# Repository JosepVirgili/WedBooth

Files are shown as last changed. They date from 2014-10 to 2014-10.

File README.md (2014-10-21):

# Wedding PhotoBooth

A nice weeding PhotoBooth for Sandra and Josep's wedding.

### Required Hardware
The required components are:

- Raspberry Pi (RPi)
- Display (about 10') with HDMI input
- HDMI cable (to connect the RPi with the display)
- Pi Camera
- Nicer camera as a DSLR
- Remote shutter for the DSLR
- USB connector for the DSLR
- Protoboard
- Jumper cables
- Push button 

### Set-up

First the RPi needs to be configured. Follow this [guide]().

When done install gphoto2:

```
wget https://raw.githubusercontent.com/gonzalo/gphoto2-updater/master/gphoto2-updater.sh
chmod +x gphoto2-updater.sh
sudo ./gphoto2-updater.sh
```

Install the bluetooth tools required to operate the PoGo printer:

```
sudo apt-get install bluez bluez-utils obexftp
```

Find the mac adress of your printer:

```
hcitool scan
```

The mac adress will appear as YY:YY:YY:YY:YY:YY Polaroid ZZ ZZ ZZ where YY:YY:YY:YY:YY:YY is the mac adress.
Then we need to include the pin code of the pogo into the system:

```
sudo mkdir /var/lib/bluetooth/YY:YY:YY:YY:YY:YY
sudo nano /var/lib/bluetooth/YY:YY:YY:YY:YY:YY/pincodes
```

Include the line `YY:YY:YY:YY:YY:YY 6000` into the file and save.

Then the software needs to be uploaded into the Raspberry Pi:

```
git clone https://github.com/JosepVirgili/WedBooth.git
```

Then, create a `settings.txt` file to save the PoGo mac adress.

```
cd WedBooth
nano settings.txt
```

Add at the beginning of the file insert the YY:YY:YY:YY:YY:YY mac adress of your PoGo.

### Start the photo-booth software

To start the software just:

```
cd WedBooth
sudo python PhotoBooth.py
```

If you want the software to start when booting then:

```
sudo nano /etc/rc.local
```

At the end of the file add (change pi for your own username if you have change it):

```
# Auto run WedBooth
cd /home/pi/WedBooth
sudo python /home/pi/WedBooth/PhotoBooth.py
```

### Legal Boring Stuff

Copyright 2014 Josep Virgili Llop

This program is free software: you can redistribute it and/or modify
it under the terms of the GNU General Public License as published by
the Free Software Foundation, either version 3 of the License, or
(at your option) any later version.

This program is distributed in the hope that it will be useful,
but WITHOUT ANY WARRANTY; without even the implied warranty of
MERCHANTABILITY or FITNESS FOR A PARTICULAR PURPOSE.  See the
GNU General Public License for more details.

You should have received a copy of the GNU General Public License
along with this program.  If not, see <http://www.gnu.org/licenses/>.

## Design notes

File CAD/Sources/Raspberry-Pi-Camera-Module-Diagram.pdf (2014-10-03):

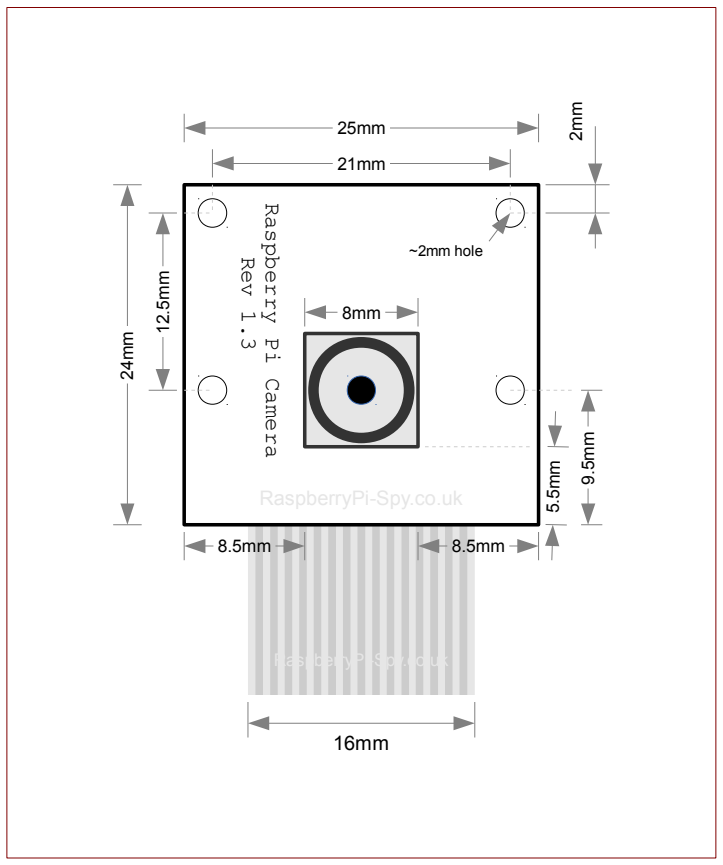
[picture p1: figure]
RaspberryPi-Spy.co.uk; Rasp; berry Pi Camera Rev 1.3; ~2mm hole

Print so that rectangle is 50mm x 60mm This will require a reduction of 50%

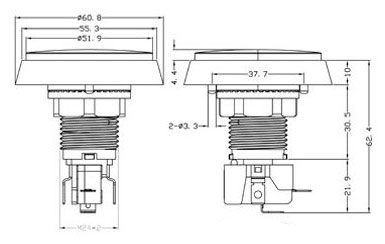
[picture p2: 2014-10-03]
CAD/Sources/Button.jpg

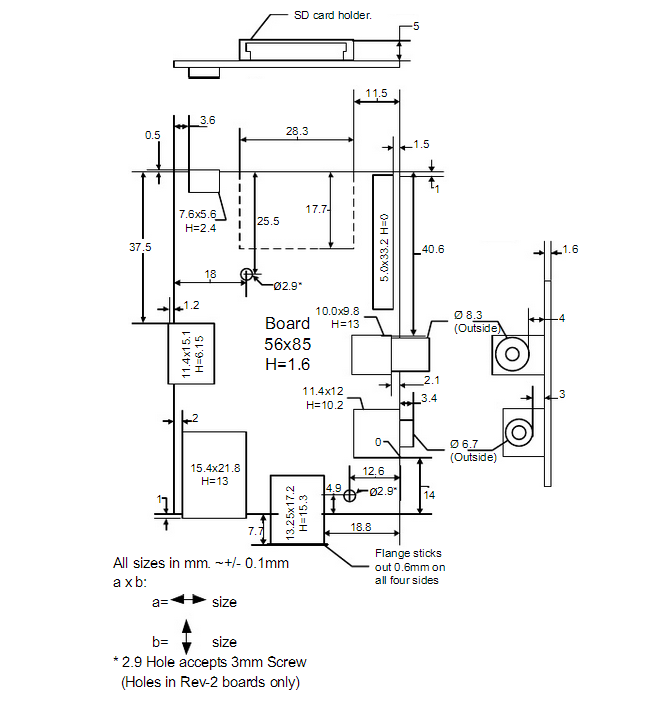
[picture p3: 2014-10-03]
CAD/Sources/PiMeasurments.png

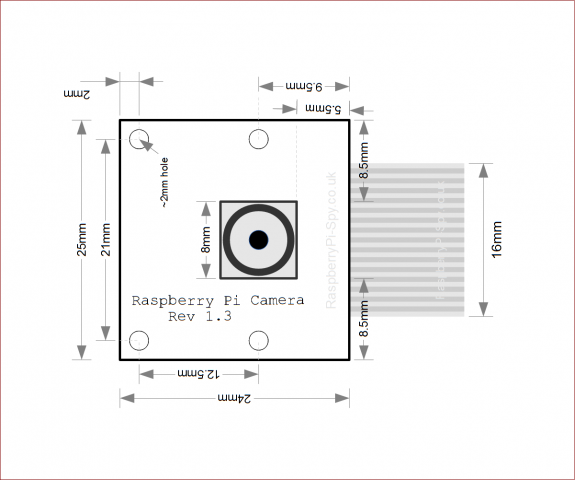
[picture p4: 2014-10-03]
CAD/Sources/Raspberry-Pi-Camera-Module-Diagram-575x480.png

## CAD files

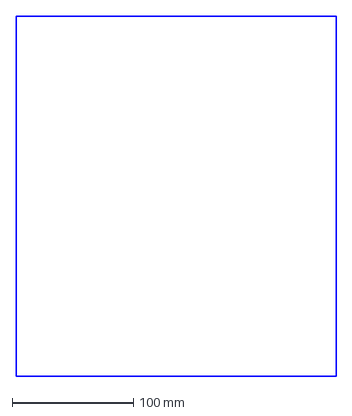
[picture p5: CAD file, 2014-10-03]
CAD/2DCAD/NoComments/Back_NoCom.dxf
264.0 x 297.0 mm

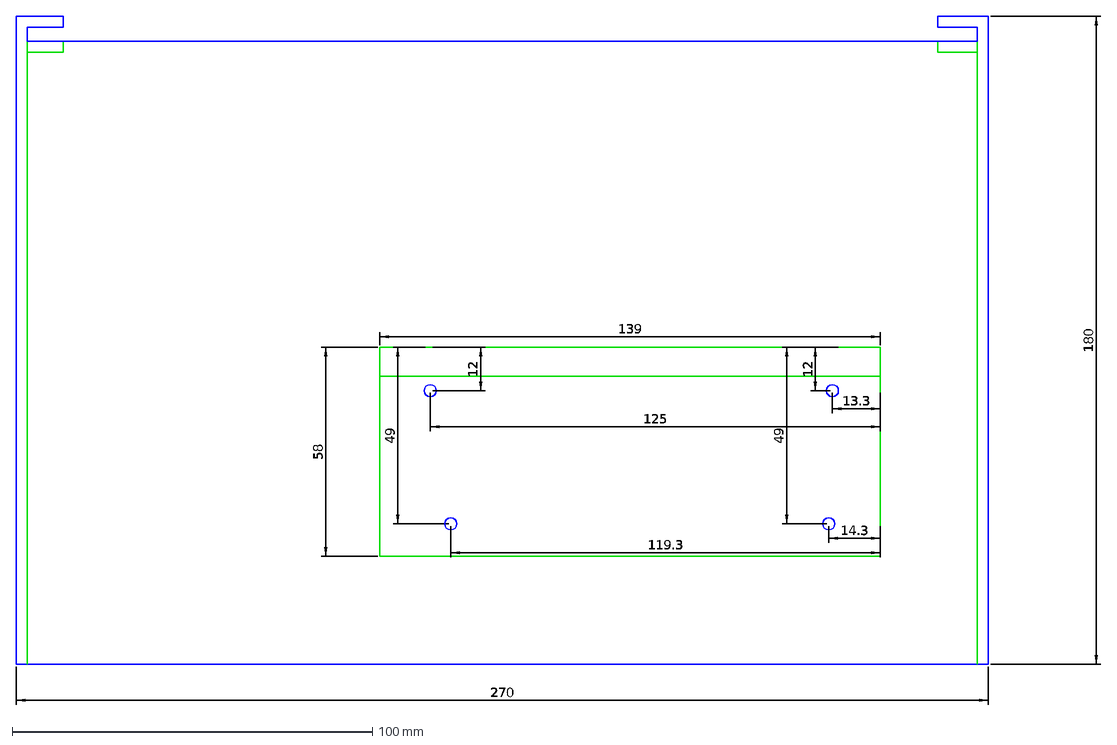
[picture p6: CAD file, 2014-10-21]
CAD/2DCAD/Top.dxf
270
12
125
49
14.3
13.3
119.3
180
139
58

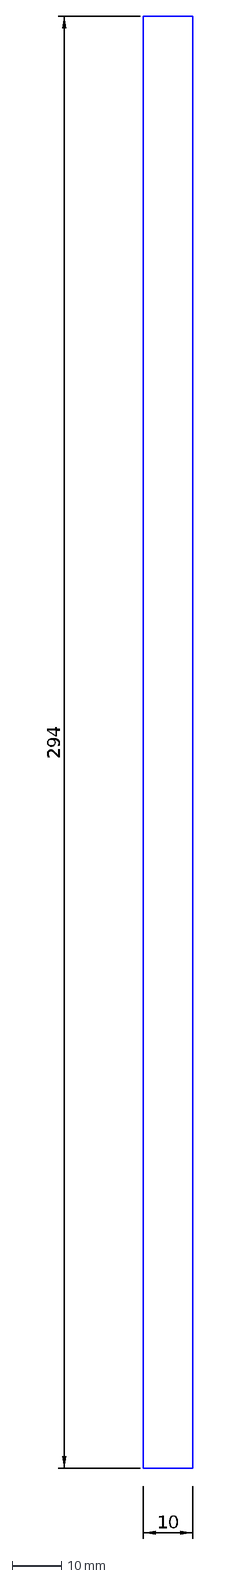
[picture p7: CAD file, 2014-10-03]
CAD/2DCAD/Block_Back_x4.dxf
10
294

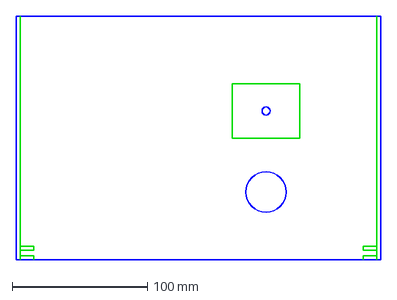
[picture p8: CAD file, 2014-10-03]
CAD/2DCAD/NoComments/Bottom_NoCom.dxf
270.0 x 180.0 mm

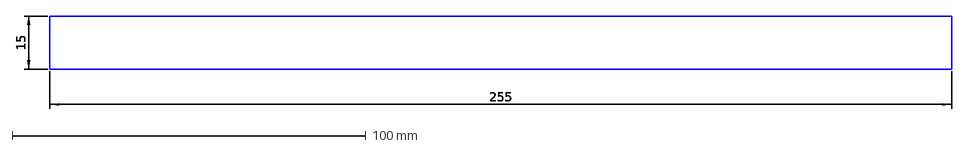
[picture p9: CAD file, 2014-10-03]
CAD/2DCAD/Block_Front_x4.dxf
255
15

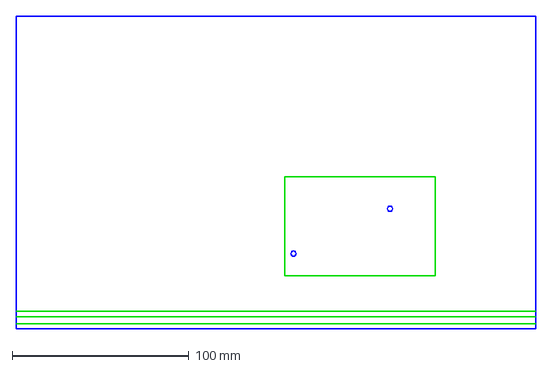
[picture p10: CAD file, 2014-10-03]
CAD/2DCAD/NoComments/Right_NoCom.dxf
294.0 x 177.0 mm

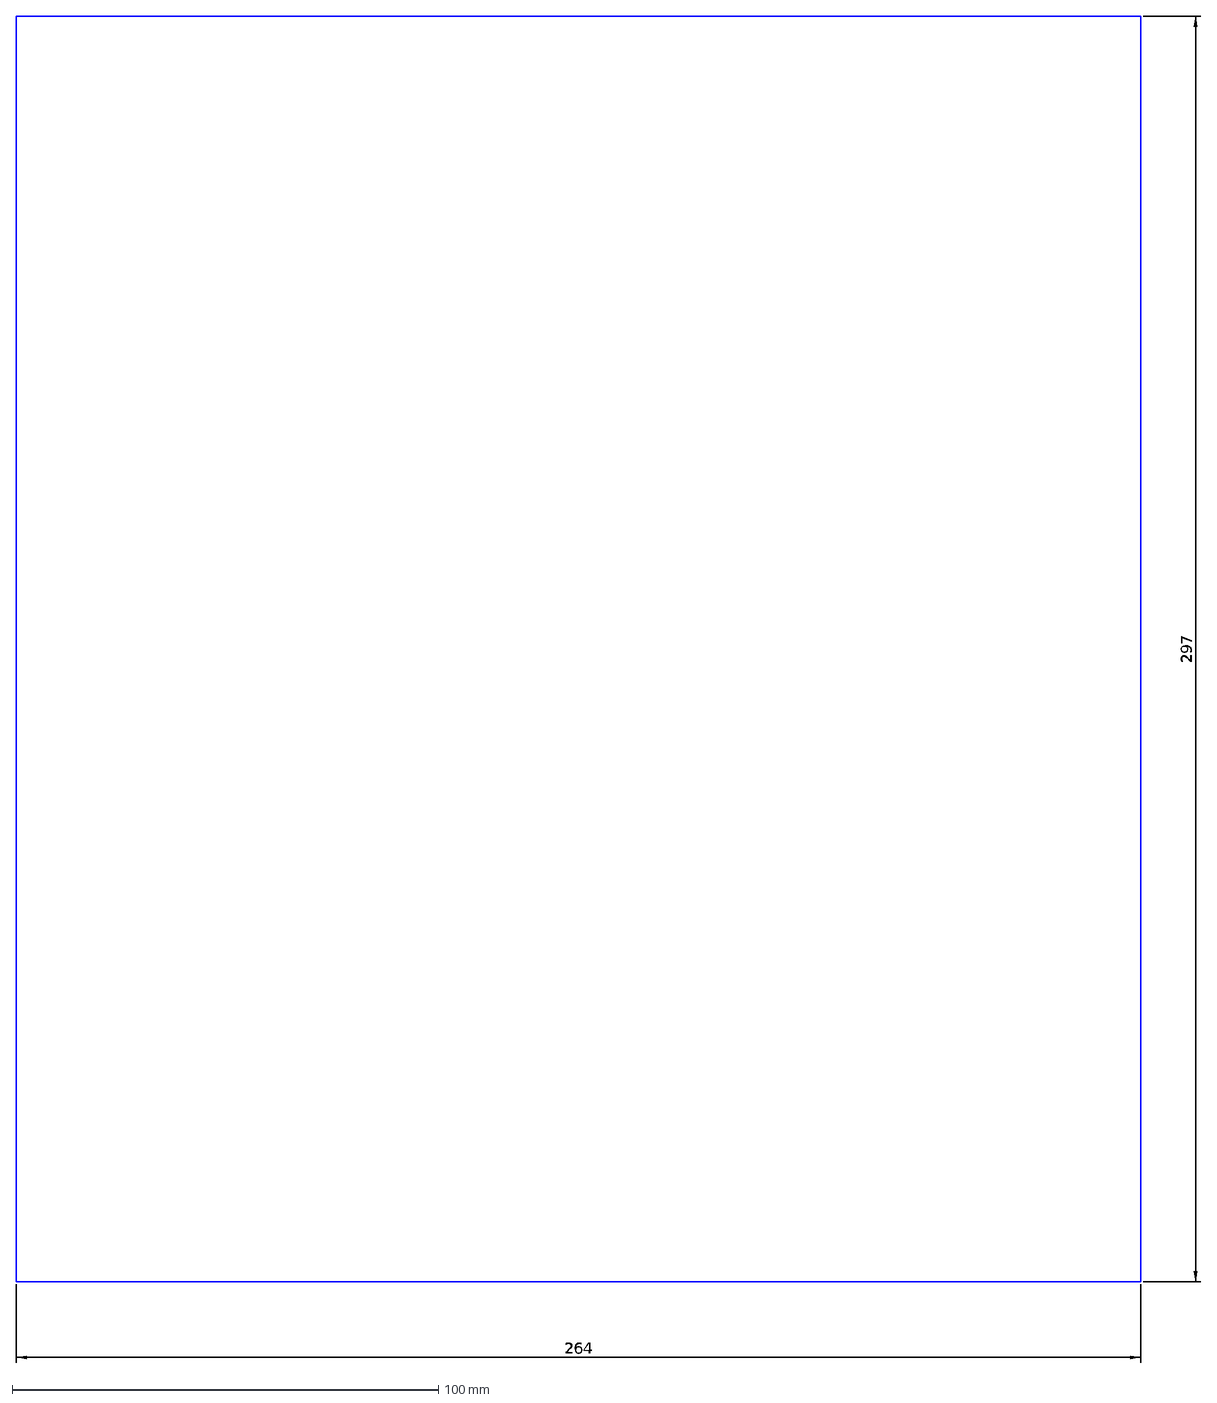
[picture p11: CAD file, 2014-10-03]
CAD/2DCAD/Back.dxf
297
264

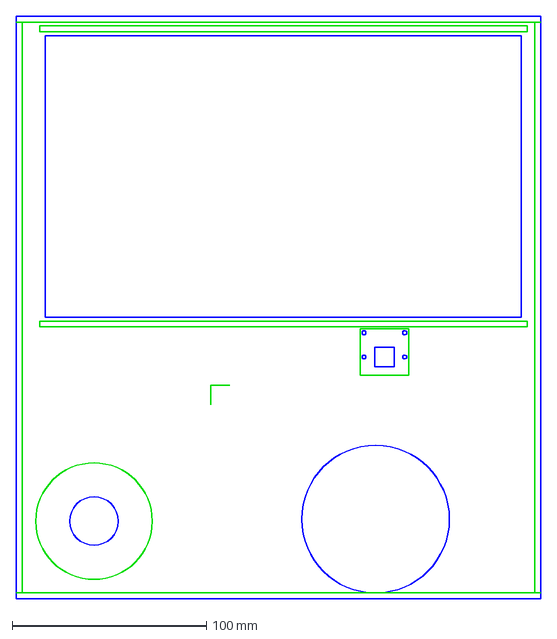
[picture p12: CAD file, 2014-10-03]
CAD/2DCAD/NoComments/Front_NoCom.dxf
270.0 x 300.0 mm

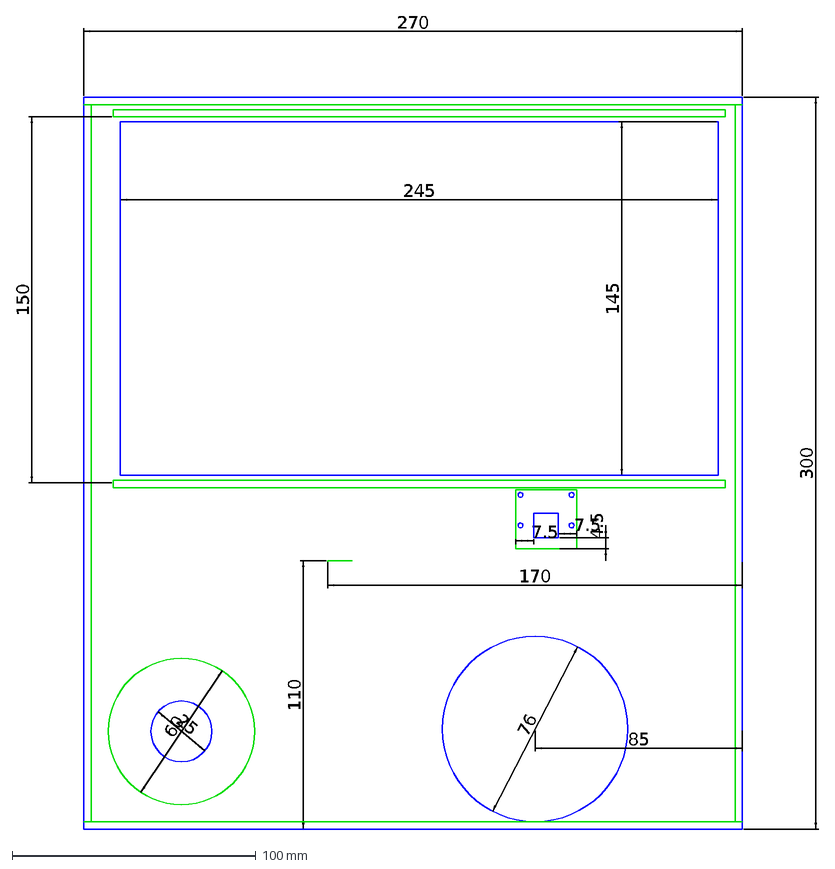
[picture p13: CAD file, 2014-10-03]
CAD/2DCAD/Front.dxf
300
245
110
170
270
150
145
4.5
7.5
60
25
85
76

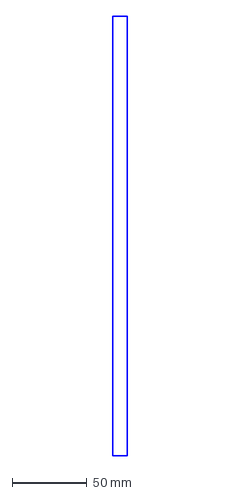
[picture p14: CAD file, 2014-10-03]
CAD/2DCAD/NoComments/Block_Back_x4_NoCom.dxf
10.0 x 294.0 mm

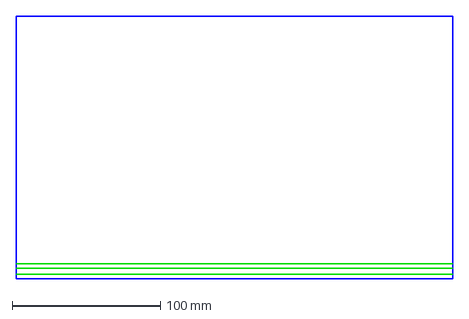
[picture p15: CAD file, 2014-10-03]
CAD/2DCAD/NoComments/Left_NoCom.dxf
294.0 x 177.0 mm

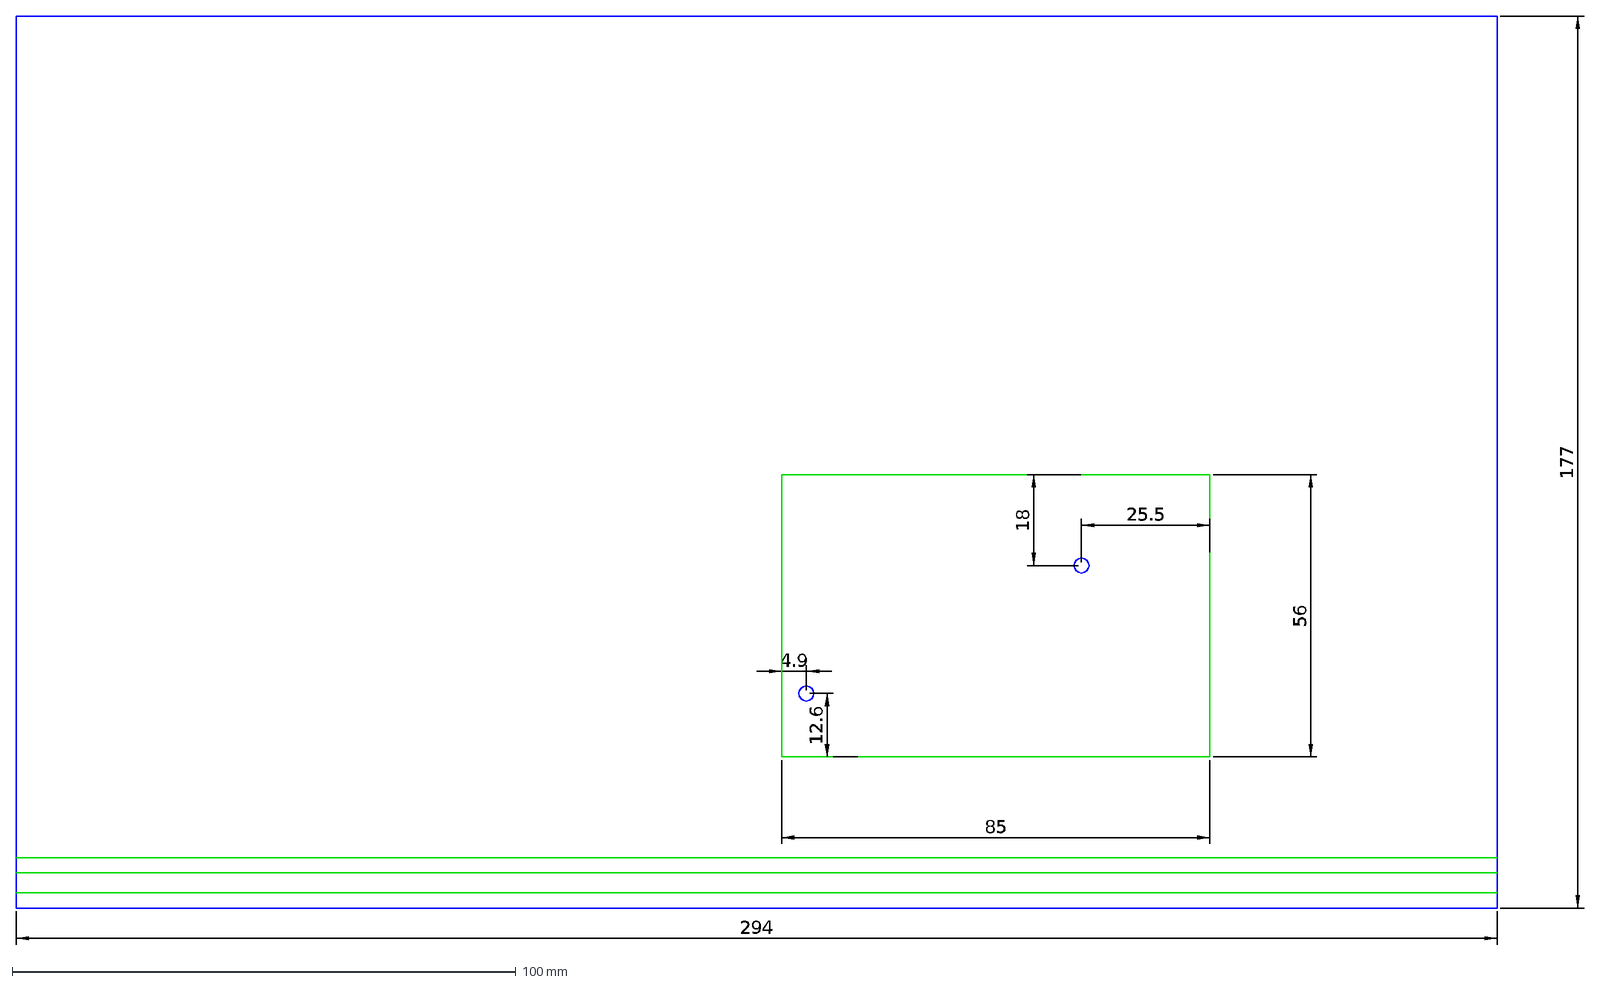
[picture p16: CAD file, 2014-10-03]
CAD/2DCAD/Right.dxf
294
177
85
12.6
4.9
56
25.5
18

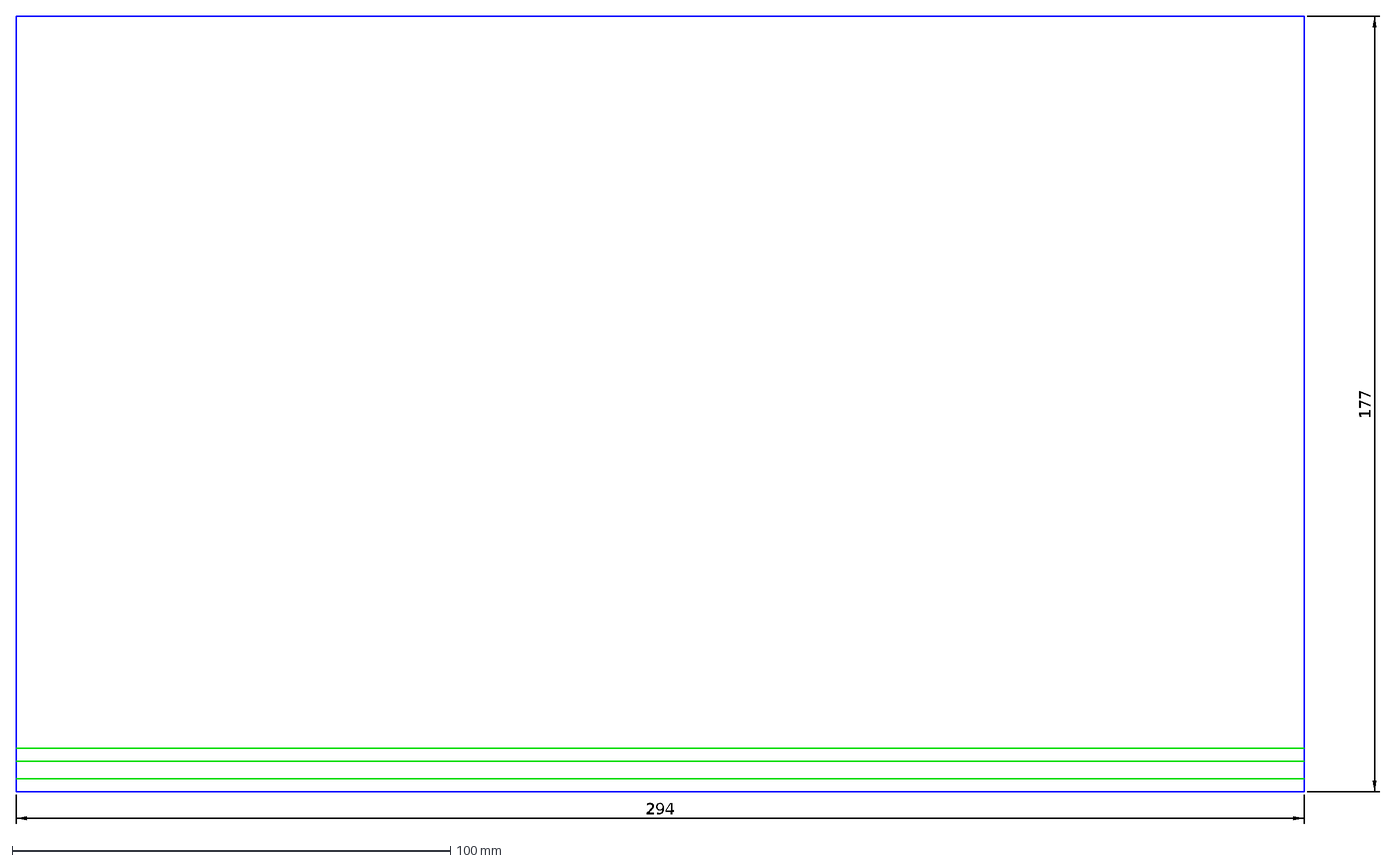
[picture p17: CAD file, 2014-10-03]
CAD/2DCAD/Left.dxf
294
177

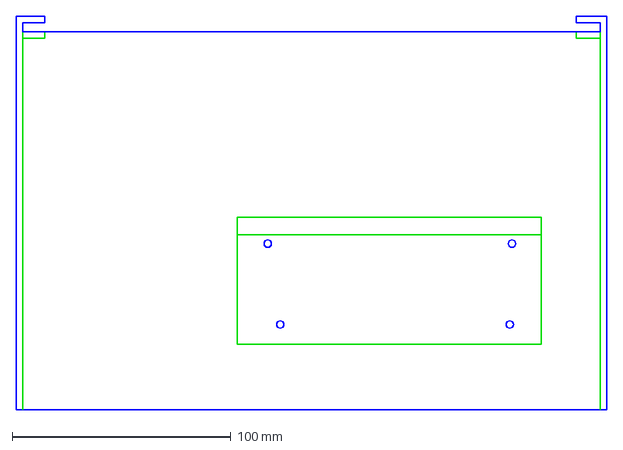
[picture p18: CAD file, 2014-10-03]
CAD/2DCAD/NoComments/Top_NoCom.dxf
270.0 x 180.0 mm

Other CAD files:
CAD/2DCAD/Bottom.dxf
CAD/2DCAD/NoComments/Block_Front_x4_NoCom.dxf

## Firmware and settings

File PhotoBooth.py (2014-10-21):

# Wedding Photo Booth Software
#
#    Copyright 2014 Josep Virgili Llop
#
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
#--- CODE ---#
import RPi.GPIO as GPIO
import time
from subprocess import call
import pygame
import picamera
import math
import io
from threading import Thread

#GPIO configuration
GPIO.setmode(GPIO.BOARD) #Set the Board Mode
GPIO.setup(7, GPIO.OUT) #Set up GPIO Pin 7 to Output to wake up camera
GPIO.output(7, False) #Not wake the camera yet
GPIO.setup(19,GPIO.IN) #Set up Pin 19 to input to detect push button

#Pygame configuration
pygame.init()
pygame.mouse.set_visible(0)
screenSize = (pygame.display.Info().current_w, pygame.display.Info().current_h)
screen = pygame.display.set_mode(screenSize,pygame.FULLSCREEN)

# Fill background
background = pygame.Surface(screen.get_size())
background = background.convert()
background.fill((0, 0, 0))

#Initialize Camera
camera = picamera.PiCamera()
cam_resolution = (1920,1080)
camera.resolution = cam_resolution
camera.framerate = 15
camera.start_preview()
camera.hflip=True
#Alpha Values
preview_alpha_CD = 200 #Countdown alpha value
preview_alpha_TXT = 150 #Text alpha value

#Set countdown text font
font_CD = pygame.font.SysFont("arial", screenSize[1])
font_TXT = pygame.font.SysFont("arial", screenSize[1]/5)


#--- Functions ---#
def ConfigureDSLR():
	#Configures the DSLR Camera
	WakeUpDSLR(1) #Wakes up the camera
	time.sleep(2) #Allow some time for the camera to mount
	call('gphoto2 --set-config imageformat=4',shell=True) #Configure Pic format to Medium Fine JPG
	call('gphoto2 --set-config capturetarget=1',shell=True) #Configure camera to save to SD
	call('gphoto2 --set-config colortemperature=5500',shell=True) #Configure color temperature
	
def ReadMAC():
	#Reads from file MAC address of the PoGo printer
	file = open('settings.txt', 'r') #Open file in read mode
	return file.read().replace('\n','') #Return MAC adress
	
def WakeUpDSLR(n):
	#Wakes up the DSLR camera
	GPIO.output(7, True) #Wake up camera
	time.sleep(n) #Sleep for n second to give the camera time to wake up
	GPIO.output(7, False) #Stop waking the camera

def TakePicDSLR(filename):
	#Takes a picture with the DSLR camera and downloads it to the RPi saving it with the specified filename
	call('gphoto2 --capture-image-and-download --keep --filename '+filename+' --force-overwrite',shell=True)
	
def TakePicDSLR_Delay(n,filename):
	#Takes a picture with the DSLR using the TakePicDSLR function after n seconds delay
	time.sleep(n) #Sleep for n seconds
	TakePicDSLR(filename) #Take picture with DSLR

def TakePicPiCamStream(camera,cam_resolution):
	#Takes a picture with the Pi camera and returns it
	stream = io.BytesIO() #Create stream
	camera.capture(stream, 'rgb', use_video_port=True) #Capture picture
	rgb = bytearray(cam_resolution[0] * cam_resolution[1] * 3) 	# Buffers for PiCamera picture
	#Read picture into buffer
	stream.seek(0)
	stream.readinto(rgb)
	#Return the image
	return pygame.image.frombuffer(rgb[0:cam_resolution[0]*cam_resolution[1]*3],cam_resolution, 'RGB')

def DisplayImageFile(filename):
	#Diplays and image from file into the display when it has transferred.
	image=pygame.image.load(filename) #Load image
	image = pygame.transform.scale(image.convert(), screenSize) #Resizes it to fit screen
	image = pygame.transform.flip(image.convert(),True,False) #Flip image horizontally
	#Diplays image in display
	screen.blit (image, (0,0))
	pygame.display.update()
	return image

def DisplayImagePi(image):
	#Display image from an image object.
	image = pygame.transform.scale(image.convert(), screenSize) #Resizes it to fit screen
	#Diplays image in display
	screen.blit(image, (0,0))
	pygame.display.update()
	return image
	
def DisplayText_Centre(text_disp,image):
	#Generate text
	text = font_TXT.render(text_disp, True, (255, 255, 255))
	textpos = text.get_rect()
	textpos.centerx = screen.get_rect().centerx
	textpos.centery = screen.get_rect().centery
	#Diplays image in display
	screen.blit(image, (0,0))
	pygame.display.update()
	#Displays text on top
	screen.blit(text, textpos)
	pygame.display.update()

def Countdown(count,background):
	#Performs countdown with preview
	cd=1 #Initialize countdown variable
	start_time = pygame.time.get_ticks() #Initialize time
	#Transparency level
	camera.preview_alpha = preview_alpha_CD
	#Remove previous text
	background.fill((0, 0, 0))
	#Start countdown
	while cd>0:
		#Establish countdown
		cd = int(math.ceil((start_time - pygame.time.get_ticks())/1000 + count+0.5))
		#Generate countdown text
		text = font_CD.render(str(cd), True, (255, 255, 255),(0,0,0))
		textpos = text.get_rect()
		textpos.centerx = background.get_rect().centerx
		background.blit(text, textpos)
		# Blit everything to the screen
		screen.blit(background, (0, 0))
		pygame.display.flip()
		
def WaitForButton(camera):
	#Waits until the button is pressed with a text indicating to press button
	
	#Transperency
	camera.preview_alpha = preview_alpha_TXT
	#Remove previous text
	background.fill((0, 0, 0))
	#Generate text
	text_1 = font_TXT.render("Push the button", True, (255, 255, 255),(0,0,0))
	textpos_1 = text_1.get_rect()
	textpos_1.centerx = background.get_rect().centerx
	textpos_1.centery = background.get_rect().centery
	text_2 = font_TXT.render("to start!", True, (255, 255, 255),(0,0,0))
	textpos_2 = text_2.get_rect()
	textpos_2.centerx = background.get_rect().centerx
	textpos_2.centery = textpos_1.centery+textpos_2.height
	background.blit(text_1, textpos_1)
	background.blit(text_2, textpos_2)
	# Blit everything to the screen
	screen.blit(background, (0, 0))
	pygame.display.flip()
	
	#Wait until a button is pressed
	while True:
		if (GPIO.input(19) == False): #Button pressed
			break

def PrintDSLR(prefix,filename):
	#Sends file to printer to start printing
	call('obexftp --nopath --noconn --uuid none --bluetooth '+mac+' --channel 1 -p '+prefix+filename,shell=True)
	
def ResizePrint(prefix,filename):
	#Resize picture for printing
	image=pygame.image.load(filename) #Load image
	image = pygame.transform.scale(image.convert(),(720,480) ) #Resizes for faster transmission
	pygame.image.save(image,prefix+filename)
	
def PrintButton(prefix,filename,image):
	#Printing process
	DisplayText_Centre('Push again to print',image)
	#Wait until a button is pressed
	start_time = pygame.time.get_ticks() #Initialize time
	while (pygame.time.get_ticks()-start_time)<7500:
		if (GPIO.input(19) == False): #Button pressed
			#Display ending to printer message
			DisplayText_Centre('Sending to Printer',image)
			#Send to Printer
			PrintDSLR(prefix,filename)
			#Display printing message
			DisplayText_Centre('Printing',image)
			#Wait an estimate of the printing process
			time.sleep(45)
			#PrintButton(prefix,filename,image)
				
def PostDSLR(prefix,filename,t_PicDSLR):
	#Kickstarts the tasks that need to be done when the picture has been taken
	#Wait until the piture has finished
	t_PicDSLR.join()
	#Resize image for potential printing
	t_Resize = Thread(target=ResizePrint,args=(prefix,filename,))
	t_Resize.start()
	#Display DSLR image
	image = DisplayImageFile(filename)
	time.sleep(5) #Allow time for unobstructed viewing
	#Finish print resize
	t_Resize.join()
	#Button to print
	PrintButton(prefix,filename,image)
	
		
def PicSequence(count,prefix,filename):
	#Sequence to take pictures with cd being the countdown time in sec (min 3 seconds) and filename the name of the picture file.
	#Generate threats
	t_PicDSLR_Delay = Thread(target=TakePicDSLR_Delay,args=(count-1.5,filename,))
	t_PostDSLR = Thread(target=PostDSLR,args=(prefix,filename,t_PicDSLR_Delay,))
	t_WakeUp = Thread(target=WakeUpDSLR,args=(count-2,))
	#Sequence
	t_WakeUp.start() #Wake up  DSLR camera
	t_PicDSLR_Delay.start() #Take picture using DSLR with a delay
	t_PostDSLR.start() #Start post DSLR image capture tasks thread
	Countdown(count,background) #Countdown
	img = TakePicPiCamStream(camera,cam_resolution) #Take picture using PiCam
	img = DisplayImagePi(img) #Display image from PiCam
	camera.preview_alpha = 0 #Set transparency of preview to 0
	DisplayText_Centre('Processing',img) #Display 'processing' text
	t_PostDSLR.join() #Wait until all the post DSLR image capture tasks have finsihed
	
#--- Main script ---#
filename = 'WedBoothPic.jpg' #Filename of the image
prefix = 'Thumb_' #Print file prefix
count = 5 #Countdown time in sec
ConfigureDSLR() #Configure DSLR
mac = ReadMAC() #Read PoGo MAC address
while True:
	WaitForButton(camera)
	PicSequence(count,prefix,filename)
	
#--- Clean up ---#
camera.close()
GPIO.cleanup() #Clean up of the GPIO Port
	
	

	
	
	

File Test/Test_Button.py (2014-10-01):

#Test if the Button Works
import RPi.GPIO as GPIO
import time
import os

#Configure GPIO pin
GPIO.setmode(GPIO.BOARD) #Set the Board Mode
GPIO.setup(19,GPIO.IN) 

#Loop and print mesage when button is pressed
while True:
	if (GPIO.input(19) == False):
		print "Button pressed"
		time.sleep(2)
		os.system('clear')
		

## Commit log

2014-08-20 Added function that wakes-up DSLR camera.
2014-08-20 Start with the pin down to avoid having it floating at startup.
    [PhotoBooth.py]
2014-08-21 The image taken by the camera is now downloaded into the disk. Added a function that displays and image from the disk into the display using pygame.
2014-09-04 Take image from PiCam and diplay it while the other is loading. Added threading for extra speed.
2014-09-30 Corrected the camera resolution to fill the screen. Removed camera set-up as it didn't work in its present form and added the sequence to capture a picture into a function.
    [PhotoBooth.py]
2014-09-30 Take picture with another thread and allow it to start before the countdown reaches 0.
2014-09-30 Added a script that wakes up the camera in order to check the GPIO connections.
2014-09-30 Changed Pi camera resolution and use video port for maximum speed and to avoid black screens.
    [PhotoBooth.py]
2014-09-30 Keep image in the Camera SD card for archiving.
2014-10-01 Added test functions in their own folder and added a function to test the push button.
2014-10-01 Take image when the button is pressed.
2014-10-01 Function to diplay image as a thread in order to increase speed if possible.
2014-10-01 Added a thread to do the post DSLR image capture tasks and added the messages.
2014-10-01 Added the procedure to make the PoGo printer work.
2014-10-03 Added first CAD drawings of structure.
    [Back.dxf, Block_Back_x4.dxf, Block_Front_x4.dxf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]
2014-10-03 Added drawings without comments.
    [Back_NoCom.dxf, Block_Back_x4_NoCom.dxf, Block_Front_x4_NoCom.dxf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]
2014-10-15 Added printing of the image.
2014-10-15 Keep images into DSLR SD and scaled down image for faster transmission to printer.
2014-10-21 Final touches to speedup printing, adjusted timings and sentences.
2014-10-21 Added missing drawing.
    [Top.dxf]
